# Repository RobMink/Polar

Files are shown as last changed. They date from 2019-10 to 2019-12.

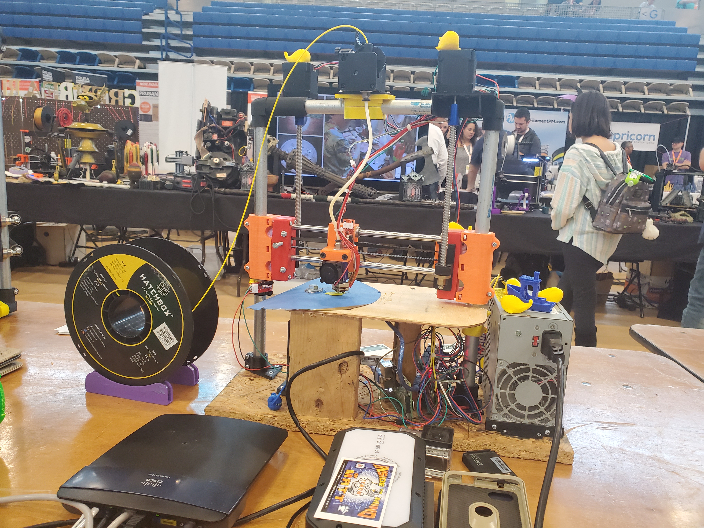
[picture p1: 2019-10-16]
20191013_131348.jpg

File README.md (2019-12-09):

DEPRECATED:  Please see polar 2 at https://www.thingiverse.com/thing:4032809

# Polar
Polar Printer
This is an unfinished Polar Printer, Demo-ed at ERRF 2019

it needs firmware work for homing xy and a better belt system.

I used a 100-1 gear reduced stepper or a belt driven stepper system, as long as no backlash is in the system it will work well.  Also, if going with a reduced stepper, use around a 25 to one instead of a 100 to one.

Inspired from Alex's Piper project, zslider IS Alex's design.

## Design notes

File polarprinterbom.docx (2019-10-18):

Three options:

1.

Print Radianprinterbase.slt

2.

Print Thetamotormount.stl

Pipemount-wire.stl

3.

As pictured – print:

Pipemount-wire.stl

Thetamotormount-justpipemount.stl

Radianprinterbase2-chopped.stl

For all, print:

Item | Number
Bed.stl or use a sheet of plywood and pipemount.stl for support | 1
PSUmount.stl if using ATX PSU and option 2 or 3 | 2
Bedtiedown if issues with bed lifting | 1 of each
Gantry-z-slider | 2
Idlerradrod | 1
Motorothersideradrod | 1
Motorradrod | 1
Radianprintercoupler if using option 1 or 3 | 1
Radiuscarrage | 1
Thetamotortop for option 1 or 3 | 1
Zmotormount | 2
Zthreadedrod | 2

Also needed are: GT2 Belt

Gt2 belt lock (small rectangle to put belt in to make it a loop) such as https://www.thingiverse.com/thing:1719926

GT2 idler pulley with 5mm center bore, same as piper2

5mm Bolt

Gt2 pulley for nema 17 motor

4 Nema 17 motors

Ramps or other control board

A home switch

V6 or Jhead

Bowden tube

Extruder such as titan

Ptfe tube for extruder and for zslider

ATX Power supply

#6 nuts and bolts

M3 nuts and bolts

Nema 17 to leadscrew (x2)

Leadscrew and nut (x2)

Nema 23 or planetary gear reduced nema 17

Brass sheeting for flexibed

608 skate bearings for bed tie down (plus 5-16 in bolts and nuts or M8 nuts and bolts)

Wood if using options 2 or 3 (plywood and 2x4s)

See https://youtu.be/Pi0Z8N-739Y

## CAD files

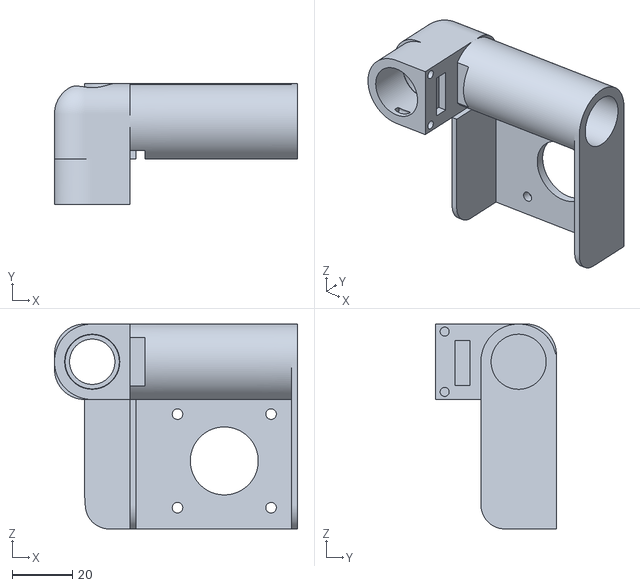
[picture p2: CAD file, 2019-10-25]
zmotormountWZmaxhomeswitch.stl
80.5 x 40.0 x 67.9

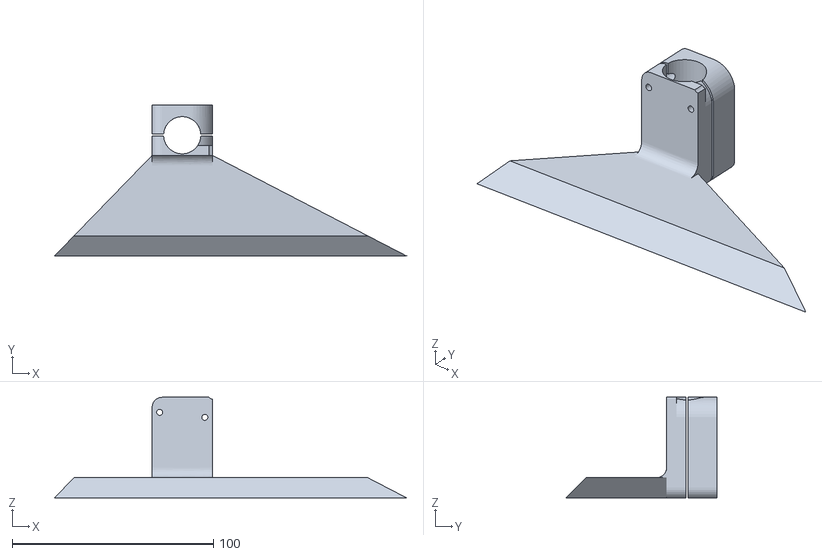
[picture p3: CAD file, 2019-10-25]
bedejector.stl
175.0 x 75.0 x 50.0

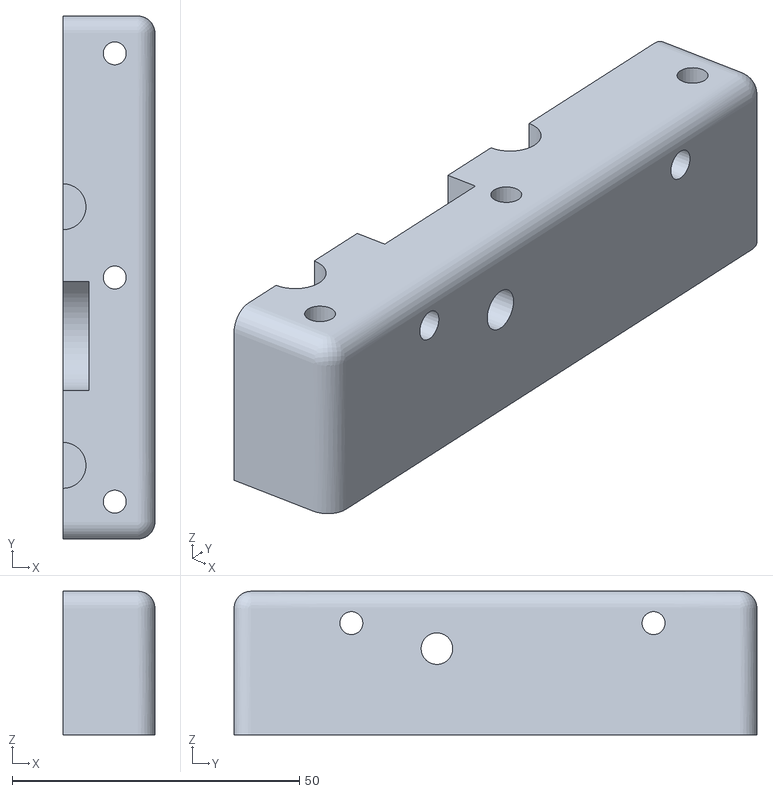
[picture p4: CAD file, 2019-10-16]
ldlerradrod.stl
16.0 x 91.0 x 25.0

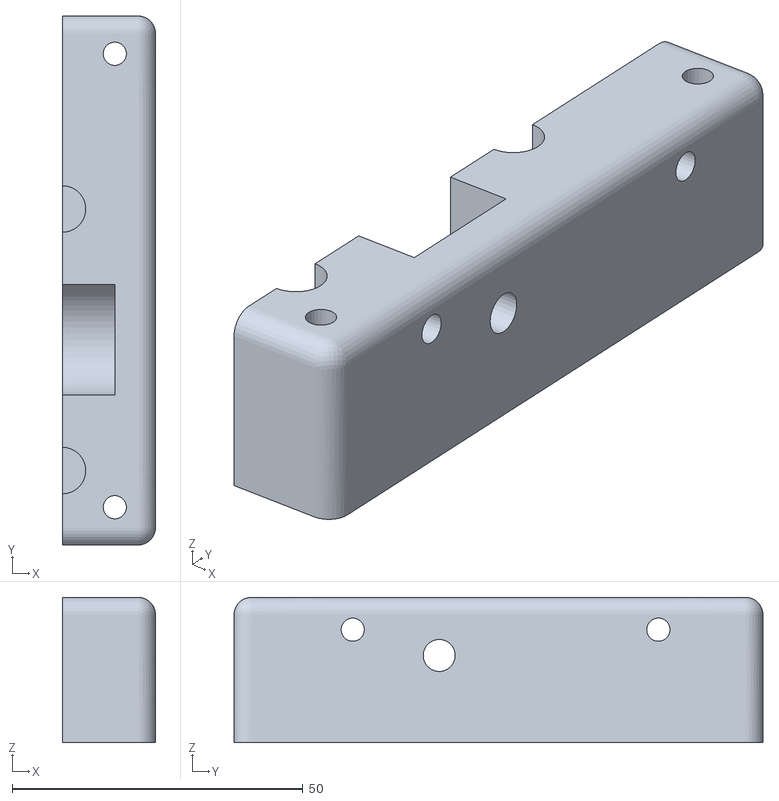
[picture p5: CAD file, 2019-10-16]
motorothersideradrod.stl
16.0 x 91.0 x 25.0

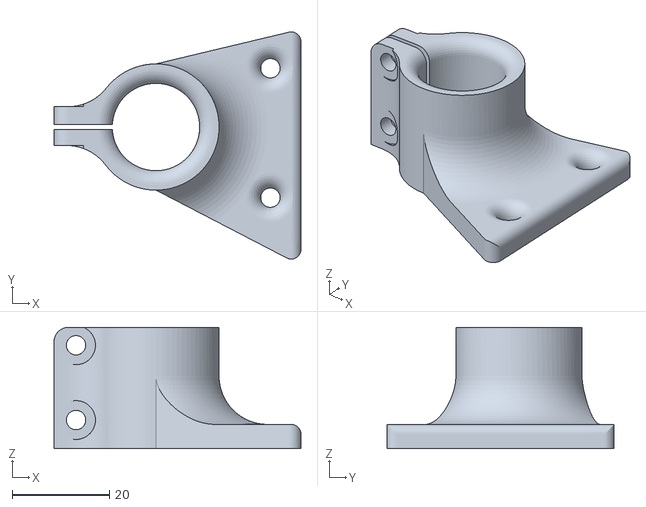
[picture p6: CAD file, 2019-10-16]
thetamotormount-justpipemount.stl
50.9 x 46.8 x 25.0

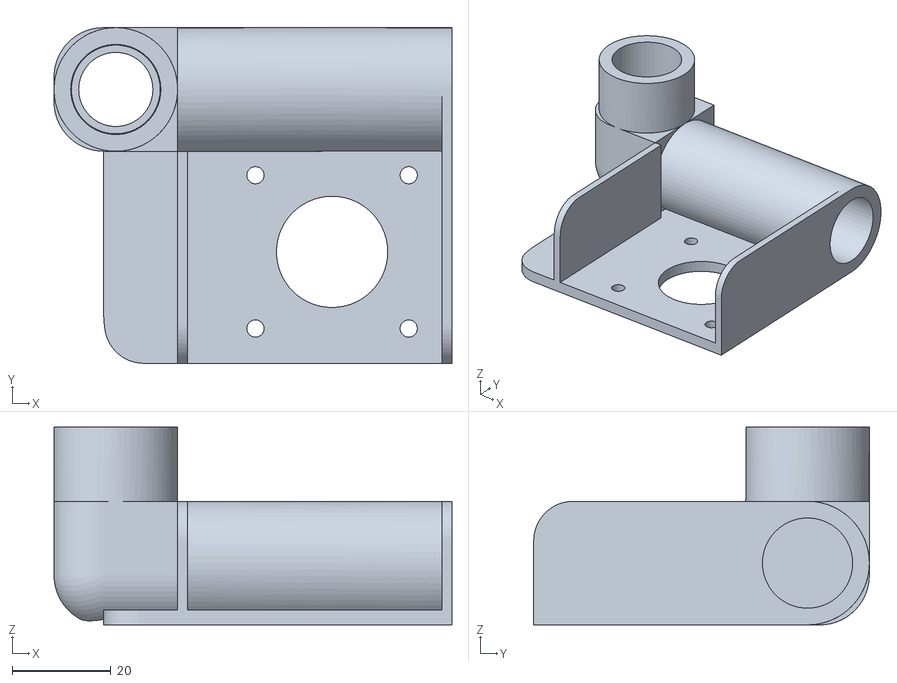
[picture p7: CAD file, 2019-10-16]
zmotormount.stl
80.5 x 67.9 x 40.0

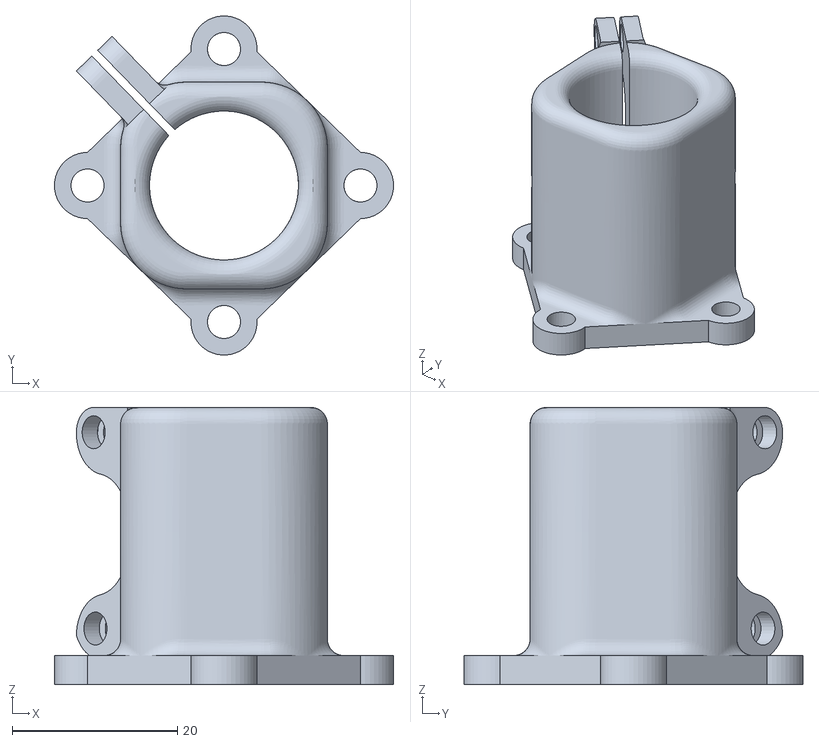
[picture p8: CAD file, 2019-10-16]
pipemount.stl
41.0 x 41.0 x 33.5

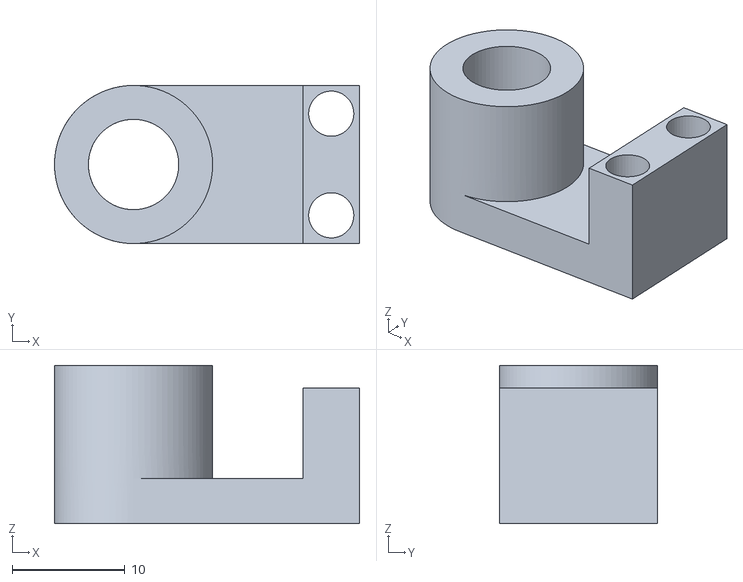
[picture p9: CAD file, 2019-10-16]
bedtiedown.stl
27.0 x 14.0 x 14.0

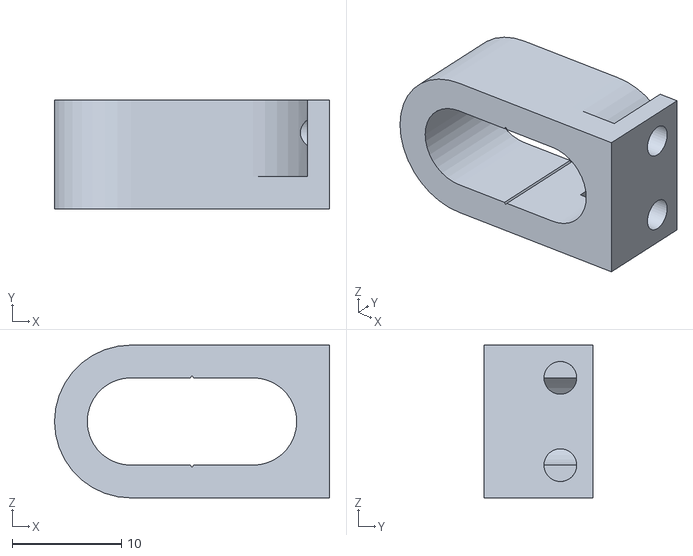
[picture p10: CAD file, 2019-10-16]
bedtiedown3.stl
25.2 x 10.0 x 14.0

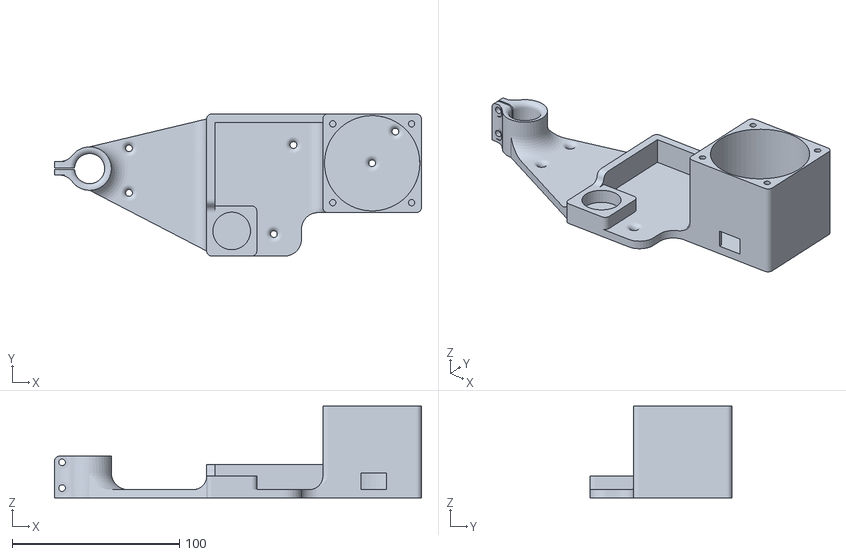
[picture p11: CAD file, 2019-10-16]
thetamotormount.stl
219.5 x 85.0 x 55.0

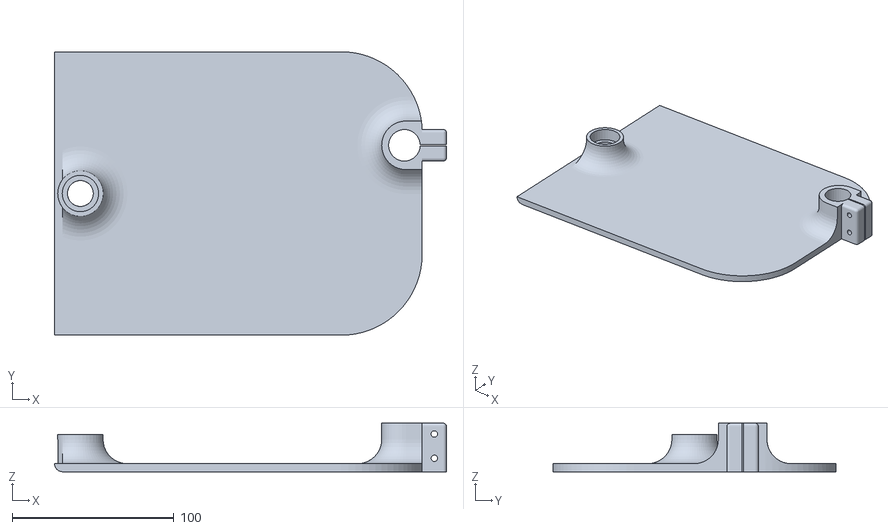
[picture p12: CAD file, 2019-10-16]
bed.stl
242.0 x 175.0 x 30.0

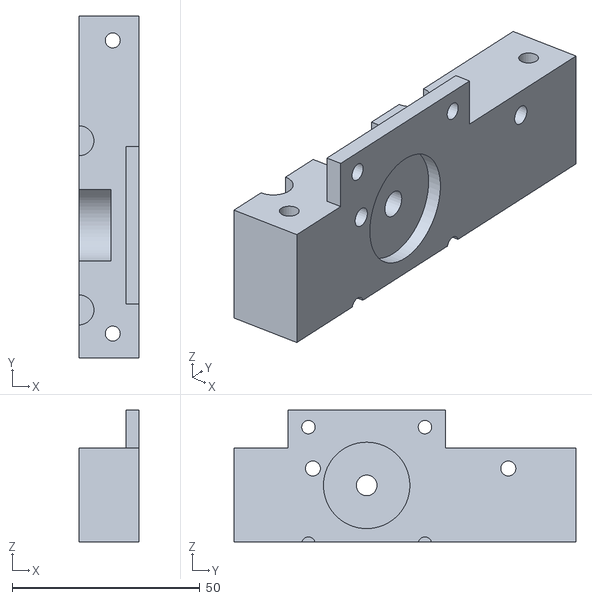
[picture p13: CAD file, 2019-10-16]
motorradrod.stl
16.0 x 91.0 x 35.0

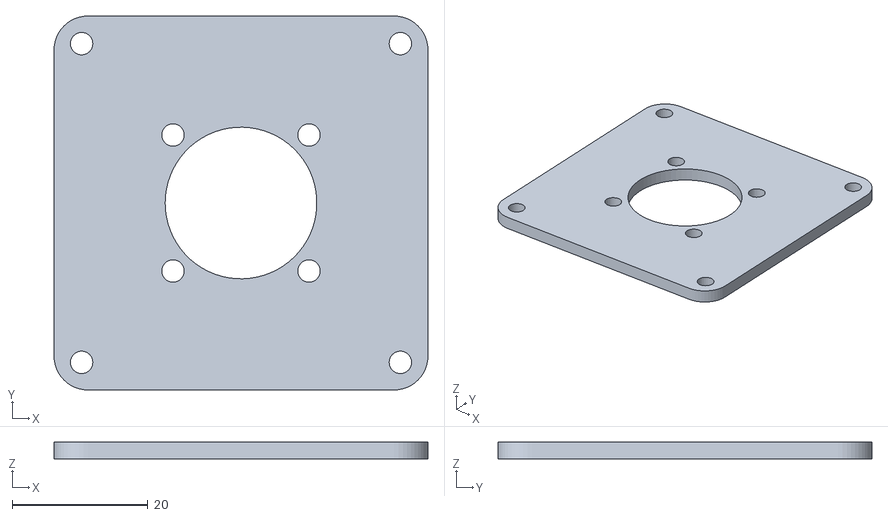
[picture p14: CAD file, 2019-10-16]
thetamotortop.stl
55.0 x 55.0 x 2.50

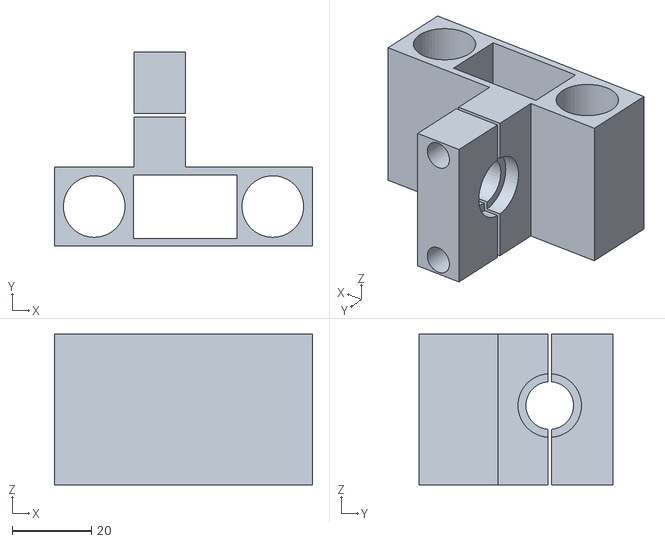
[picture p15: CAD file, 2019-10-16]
radiuscarrage.stl
65.0 x 49.0 x 38.0

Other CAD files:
zmotormount2.stl
PSUMount.stl
pipemount-wire.stl
zthreadedrod.stl
PSUMount.ipt
bed.ipt
bedtiedown.ipt
bedtiedown2.ipt
bedtiedown2.stl
bedtiedown3.ipt
gantry-Z-slider.stl
hubholder.ipt
ldlerradrod.ipt
motorothersideradrod.ipt
motorradrod.ipt
pipemount-wire.ipt
pipemount.ipt
radianprinter.iam
radianprinterbase2-chopped.stl
radianprinterbase2.ipt
radianprinterbase2.stl
radianprintercoupler.ipt
radianprintercoupler.stl
radiouscarrage.stl
radiuscarrage.ipt
thetamotormount.ipt
thetamotortop.ipt
zmotormount.ipt
zthreadedrod.ipt

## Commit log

2019-10-16 Add files via upload
    Some options exist for the bottom, either as an all in one base, or a belt base, or just a reduced stepper base on wood.
    [PSUMount.ipt, PSUMount.stl, bed.ipt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]
2019-10-16 Add files via upload
    added pic of assembled printing printer
2019-10-25 Add files via upload
    updated polar firmware and added scraper and zhomeswitch
    [bedejector.stl, zmotormountWZmaxhomeswitch.stl]
